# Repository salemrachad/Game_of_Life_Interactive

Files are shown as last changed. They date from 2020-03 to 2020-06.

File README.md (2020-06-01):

<p align="center">

</p>
                                          Interactive Painting

**I am building an interactive painting for my digital fabrication masters @ IED Madrid**  
check complete documentation on my wiki page : *https://github.com/salemrachad/Interactive_Painting/wiki*

* The IoT interactive painting can hang by your front door or a hallway...
When the painting senses motion, i.e someone exiting/entering the apartment it
will display the Weather Information or snap a picture and use it as the initial
state for Conway's Game of life.  Where the idea is that life doesn't only happen to you.
At some level you create it. So your presence is essence in that exchange.
  * *https://github.com/salemrachad/Interactive_Painting/wiki/0.0-Concept*

* I am going to be using an Arduino nano 33 IoT to control WS2812b LED displays. It has a 
good price bends for creative shaping can connect multiple matrixes together and easily controlled
by the fastLED or Neopixel Library. Every LED on that requires 5 mA so make sure to do the correct calculations
and chose the correct power supply.
  * *https://github.com/salemrachad/Interactive_Painting/wiki/0.1-Setup*

* I am using openWeather API call to get the weather information needed.
  * *https://github.com/salemrachad/Interactive_Painting/wiki/1.0-Weather-Sprites*
  * *https://github.com/salemrachad/Interactive_Painting/wiki/1.2-WIFI---API---JSON*

* The Game of Life, also known simply as Life, is a cellular automaton devised by the British mathematician 
John Horton Conway in 1970. It is a zero-player game, meaning that its evolution is determined by its
initial state, requiring no further input.  
  * *https://github.com/salemrachad/Interactive_Painting/wiki/2.0-GOL-Rules*

* I am using Processing.exe to analyze color information and translate the image taken by the webcam to a 32 x 32 2D Matrix then pass it through serial to the Arduino. Sending a 1024 byte size array is a bit tricky and I am still working on it.
  * *https://github.com/salemrachad/Interactive_Painting/wiki/3.0-Interactive-display*

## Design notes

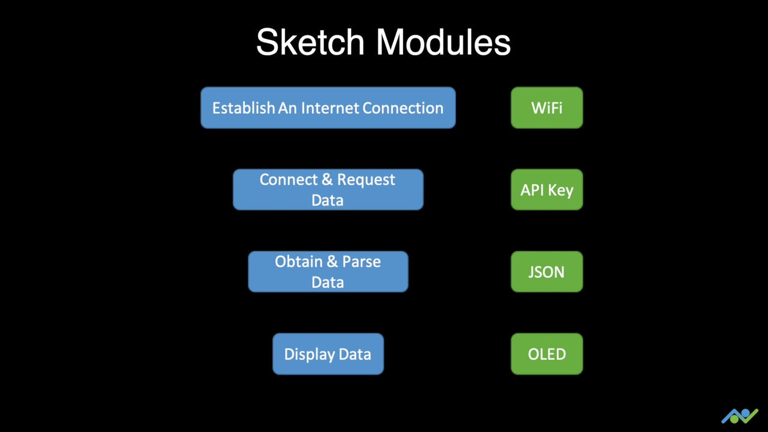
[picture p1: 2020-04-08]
Images/Wifi-Weather-Sketch.png

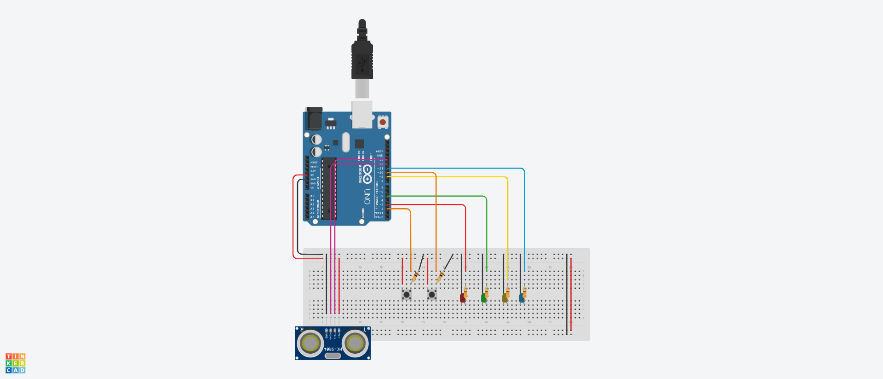
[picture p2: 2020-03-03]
Images/Arduino_Circuit.png

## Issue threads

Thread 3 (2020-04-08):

Lag when switching Cases

salemrachad, 2020-04-08:
I am having lag when switching between cases 1 and case 2.

salemrachad, 2020-04-12:
New issue when switching from Case 2 to Case 0 - Display Lag while connecting to openWeatherApi - not sure how to solve it yet

salemrachad, 2020-04-15:
Solved Lag between cases - I am having 5-10 sec of lag cycling from case 2 and case 1 - but that is the time for the HTTP request() to send and receive information - not sure if can make faster but I'll consider that issue closed for now

Closed 2020-04-15.

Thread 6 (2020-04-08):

Weather display

salemrachad, 2020-04-08:
After pulling weather data - I have to work on weather display on 32x32 LED matrix to represent weather. have 7 cases to work on

salemrachad, 2020-04-12:
Got the display to work from weather info - Still a primitive color display but will be changing it later on during the process.

salemrachad, 2020-04-15:
Initiated FastLED library to display processed images that I can store in Arduino Flash memory - using hexadecimal code

salemrachad, 2020-04-15:
Implemented only a Sun picture, for now, to see if it works and it was a SUCCESS - working on other weather display icons now.

salemrachad, 2020-04-16:
DONE!

Closed 2020-04-16.

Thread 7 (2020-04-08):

Send 2dArrat from Processing to Arduino Still not working

salemrachad, 2020-04-08:
I'm still figuring out how to send a 2d array via serial communication from processing to Arduino.
I start by sending a request from Arduino for 1 frame.
Hopefully, if I get this working I will implement many frames and make an interactive painting

salemrachad, 2020-04-15:
Case 2 - is activating a push buttonrequest from serial from Arduino part - and waiting for processing to answer - Still working on the code as it is not sending proper values

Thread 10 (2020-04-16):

Sprite animation stop before new httprequest

salemrachad, 2020-04-16:
Sprite animation is stopping before the new HTTP request. So I am having 1 frame display for 10 to 20 seconds before new weather information comes in. Trying to find a work around.

salemrachad, 2020-04-19:
Solved but now gstate can change while sprite animation is playing - trying different solutions.

salemrachad, 2020-04-21:
Cleared by extending sprite animation passtime

Closed 2020-04-21.

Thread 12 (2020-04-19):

deserializeJson() failed: NoMemory

salemrachad, 2020-04-19:
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

Sometimes serial is running this error --

salemrachad, 2020-04-21:
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

seems like there is enough memory- still trying to find a work around

salemrachad, 2020-04-21:
found a typing error - Last JSON_OBJECT_SIZE(14)+280 - change to JSON_OBJECT_SIZE(13)+270 and that solved it

Closed 2020-04-21.

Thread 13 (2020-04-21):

Change state button stuck again in Sprite animation

salemrachad, 2020-04-21:

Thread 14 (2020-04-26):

Add more narrative to help people understand the project in full

dcuartielles, 2020-04-26:
Hej,

I love your documentation, but if I didn't know what the project is all about, it would be really hard to understand what it is all about.

Please use a couple more hours in adding some narrative to your wiki, add licenses to the code, and then let's try to promote your project at e.g. the Arduino Blog and the like ;-)

/d

salemrachad, 2020-04-27:
Hey David,

I really appreciate it! I will be working on the repository and wiki this
week to make it clearer. As far as licensing goes, I am not sure how to
proceed. If you can point me in the right direction it would be great.

thank you

On Sun, Apr 26, 2020 at 11:06 AM dcuartielles <notifications@github.com>
wrote:

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

--
*Rachad Salem*
Architect

+1-714-350-1375

salemrachad@gmail.com

www.rachadsalem.com

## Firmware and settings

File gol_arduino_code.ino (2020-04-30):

///////////////////////////////////////////////////////////////////////////////////////////////////////////
// * Interactive Painting with 3 States
// *
// * State 0 gets weather information from OpenWeatherMap API and display
// * State 1 plays the game of GameofLife
// * State 2 is an interactive state using processing and webcam
// *
// * Written for the Arduino Nano 33 IoT Board and 4 x Longrunner WS2812B
// *
// * By Rachad Salem
//////////////////////////////////////////////////////////////////////////////////////////////////////////

//Wifi Setup

#include <WiFiNINA.h>
#include <ArduinoJson.h>
#include "arduino_secrets.h"
#include <stdio.h>
#include <SPI.h>

char ssid[] = SECRET_SSID;        // your network SSID (name)
char pass[] = SECRET_PASS;    // your network password (use for WPA, or use as key for WEP)
char api[] = OPENWEATHER_API; // your OpenWeatherMap API

int status = WL_IDLE_STATUS;

// Initialize the Wifi client library
WiFiSSLClient client;

unsigned long lastConnectionTime = 0;            // last time you connected to the server, in milliseconds
const unsigned long postingInterval = 30L * 1000L; // delay between updates, in milliseconds

//////////////////////////////////////////////////////////////////////////////////////////////////////////

//LED Setup - implementing Adafruit_NeoPixel and FastLED

#include <Adafruit_NeoPixel.h> //Adafruit_NeoPixel Library to display GameofLife_ram
#include "FastLED.h"       // Fastled library to control the LEDs
#include <avr/pgmspace.h>  // Needed to store stuff in Flash using PROGMEM

//DEFINE MATRIX 32x32
#define WIDTH 32
#define HEIGHT 32
#define PIN 6
#define NUMPIXELS 1024

Adafruit_NeoPixel pixels = Adafruit_NeoPixel(NUMPIXELS, PIN, NEO_GRB + NEO_KHZ800);

//color of the dots ({red, green, blue} max value 255 each] - Adafruit_NeoPixel
int colorOfPattern[3] = {25, 0, 25};
//color of background - Adafruit_NeoPixel
int colorOfBackground[3] = {0, 0, 0};
//Array for FastLed Matrix
CRGB leds[NUMPIXELS];
//////////////////////////////////////////////////////////////////////////////////////////////////////////

// Button Setup

const int buttonPin = 2; //Pause Button
int buttonState;
int lastButtonState = LOW;

const int buttonPin10 = 10; //Reset array Button
int buttonState10;
int lastButtonState10 = LOW;

const int buttonPin11 = 11; // Request Array from Processing Button
int buttonState11;
int lastButtonState11 = LOW;

const int buttonPin12 = 12; //State Changer Button
int buttonState12;
int lastButtonState12 = LOW;

// the following variables are unsigned longs because the time, measured in
// milliseconds, will quickly become a bigger number than can be stored in an int.
unsigned long lastDebounceTime = 0;  // the last time the output pin was toggled
unsigned long debounceDelay = 50;    // the debounce time; increase if the output flickers

//////////////////////////////////////////////////////////////////////////////////////////////////////////

//LED Setup

const int ledPin3 = 3; // RED Led Pin
int ledState3 = LOW;
const int ledPin5 = 5; // Green Led Pin
int ledState5 = LOW;
const int ledPin9 = 9; // Yellow Led Pin
int ledState9 = LOW;


//RGB LED setup - Display general Status by color

int Red_PIN = 14;    // gstatus 0
int Green_PIN = 15; // gstatus 1
int Blue_PIN = 16;//gstatus 2

//////////////////////////////////////////////////////////////////////////////////////////////////////////

//2d array

boolean array1[WIDTH][HEIGHT] ;
boolean cellbuffer[WIDTH][HEIGHT];

//////////////////////////////////////////////////////////////////////////////////////////////////////////

// Probability

float Probability = 45;

//////////////////////////////////////////////////////////////////////////////////////////////////////////

// Variables for timer

boolean pause = false;
int interval = 200;
int lastRecordedTime = 0;

//////////////////////////////////////////////////////////////////////////////////////////////////////////

//Variable for State
//implementing 3 states
//state 0 will Play game of life
//state 1 will display weather information on Led from OpenWeatherMap via Wifi
//state 2 will be an interactive LED - using processing and a webcam -

int gstate = 0;

///////////////////////////////////////////////////////////////////////////////////////////////////////////////////////////////////////////////////////////////////////////////////////////////////////////////////////////////////////////////////////////////////////////////////////////////////////////////////////////////////////

//Flash memory Stored Pictures for Weather Display

const long Clear1[] PROGMEM =
{
  0x99ccff, 0x99ccff, 0x99ccff, 0x99ccff, 0x99ccff, 0x99ccff, 0x99ccff, 0x99ccff, 0x99ccff, 0x99ccff, 0x99ccff, 0x99ccff, 0x99ccff, 0x99ccff, 0x99ccff, 0x99ccff, 0x99ccff, 0x99ccff, 0x99ccff, 0x99ccff, 0x99ccff, 0x99ccff, 0x99ccff, 0x99ccff, 0x99ccff, 0x99ccff, 0x99ccff, 0x99ccff, 0x99ccff, 0x99ccff, 0x99ccff, 0x99ccff,
  0x99ccff, 0x99ccff, 0x99ccff, 0x99ccff, 0x99ccff, 0x99ccff, 0x99ccff, 0x99ccff, 0x99ccff, 0x99ccff, 0x99ccff, 0x99ccff, 0x99ccff, 0x99ccff, 0x99ccff, 0x99ccff, 0x99ccff, 0x99ccff, 0x99ccff, 0x99ccff, 0x99ccff, 0x99ccff, 0x99ccff, 0x99ccff, 0x99ccff, 0x99ccff, 0x99ccff, 0x99ccff, 0x99ccff, 0x99ccff, 0x99ccff, 0x99ccff,
  0x99ccff, 0x99ccff, 0x99ccff, 0x99ccff, 0x99ccff, 0x99ccff, 0x99ccff, 0x99ccff, 0x99ccff, 0x99ccff, 0x99ccff, 0x99ccff, 0x99ccff, 0x99ccff, 0x99ccff, 0x99ccff, 0x99ccff, 0x99ccff, 0x99ccff, 0x99ccff, 0x99ccff, 0x99ccff, 0x99ccff, 0x99ccff, 0x99ccff, 0x99ccff, 0x99ccff, 0x99ccff, 0x99ccff, 0x99ccff, 0x99ccff, 0x99ccff,
  0x99ccff, 0x99ccff, 0x99ccff, 0x99ccff, 0x99ccff, 0x99ccff, 0x99ccff, 0x99ccff, 0x99ccff, 0x99ccff, 0x99ccff, 0x99ccff, 0x99ccff, 0x99ccff, 0x99ccff, 0x99ccff, 0x99ccff, 0x99ccff, 0x99ccff, 0xffffff, 0xffffff, 0xffffff, 0xffffff, 0xffffff, 0xffffff, 0xffffff, 0x99ccff, 0x99ccff, 0x99ccff, 0x99ccff, 0x99ccff, 0x99ccff,
  0x99ccff, 0x99ccff, 0x99ccff, 0x99ccff, 0xffffff, 0xffffff, 0x99ccff, 0x99ccff, 0x99ccff, 0x99ccff, 0x99ccff, 0x99ccff, 0xffffff, 0xffffff, 0xffffff, 0x99ccff, 0x99ccff, 0x99ccff, 0x99ccff, 0x99ccff, 0x99ccff, 0x99ccff, 0x99ccff, 0x99ccff, 0x99ccff, 0x99ccff, 0x99ccff, 0x99ccff, 0x99ccff, 0x99ccff, 0x99ccff, 0x99ccff,
  0x99ccff, 0x99ccff, 0xffffff, 0x99ccff, 0x99ccff, 0x99ccff, 0x99ccff, 0x99ccff, 0x99ccff, 0x99ccff, 0x99ccff, 0x99ccff, 0x99ccff, 0x99ccff, 0x99ccff, 0x99ccff, 0xffffff, 0xffffff, 0x99ccff, 0x99ccff, 0x99ccff, 0x99ccff, 0x99ccff, 0x99ccff, 0x99ccff, 0x99ccff, 0x99ccff, 0x99ccff, 0xffffff, 0xffffff, 0x99ccff, 0x99ccff,
  0x99ccff, 0x99ccff, 0xffffff, 0x99ccff, 0x99ccff, 0x99ccff, 0x99ccff, 0x99ccff, 0x99ccff, 0x99ccff, 0x99ccff, 0x99ccff, 0x99ccff, 0x99ccff, 0x99ccff, 0xffffff, 0xffffff, 0x99ccff, 0x99ccff, 0x99ccff, 0x99ccff, 0x99ccff, 0x99ccff, 0x99ccff, 0x99ccff, 0x99ccff, 0x99ccff, 0x99ccff, 0xffffff, 0xffffff, 0x99ccff, 0x99ccff,
  0x99ccff, 0x99ccff, 0x99ccff, 0xffffff, 0x99ccff, 0x99ccff, 0x99ccff, 0x99ccff, 0x99ccff, 0x99ccff, 0x99ccff, 0x99ccff, 0x99ccff, 0x99ccff, 0xffffff, 0xffffff, 0x99ccff, 0x99ccff, 0x99ccff, 0x99ccff, 0x99ccff, 0x99ccff, 0x99ccff, 0x99ccff, 0x99ccff, 0x99ccff, 0x99ccff, 0x99ccff, 0x99ccff, 0xffffff, 0x99ccff, 0x99ccff,
  0x99ccff, 0x99ccff, 0x99ccff, 0x99ccff, 0x99ccff, 0x99ccff, 0x99ccff, 0x99ccff, 0x99ccff, 0x99ccff, 0x99ccff, 0x99ccff, 0x99ccff, 0x99ccff, 0x99ccff, 0x99ccff, 0x99ccff, 0xffffff, 0xffffff, 0x99ccff, 0x99ccff, 0x99ccff, 0x99ccff, 0x99ccff, 0x99ccff, 0x99ccff, 0xffffff, 0xffffff, 0x99ccff, 0x99ccff, 0x99ccff, 0x99ccff,
  0x99ccff, 0x99ccff, 0x99ccff, 0x99ccff, 0x99ccff, 0xffffff, 0xffffff, 0xffffff, 0x99ccff, 0x99ccff, 0x99ccff, 0xffffff, 0xffffff, 0xffffff, 0x99ccff, 0x99ccff, 0x99ccff, 0x99ccff, 0x99ccff, 0x99ccff, 0x99ccff, 0x99ccff, 0x99ccff, 0x99ccff, 0x99ccff, 0x99ccff, 0x99ccff, 0x99ccff, 0x99ccff, 0x99ccff, 0x99ccff, 0x99ccff,
  0x99ccff, 0x99ccff, 0x99ccff, 0x99ccff, 0x99ccff, 0x99ccff, 0x99ccff, 0x99ccff, 0x99ccff, 0x99ccff, 0x99ccff, 0x99ccff, 0x99ccff, 0x99ccff, 0x99ccff, 0x99ccff, 0x99ccff, 0x99ccff, 0x99ccff, 0x99ccff, 0xffffff, 0xffffff, 0xffffff, 0xffffff, 0xffffff, 0x99ccff, 0x99ccff, 0x99ccff, 0x99ccff, 0x99ccff, 0x99ccff, 0x99ccff,
  0x99ccff, 0x99ccff, 0x99ccff, 0x99ccff, 0x99ccff, 0x99ccff, 0x99ccff, 0x99ccff, 0x99ccff, 0x99ccff, 0x99ccff, 0x99ccff, 0x99ccff, 0x99ccff, 0x99ccff, 0x99ccff, 0x99ccff, 0x99ccff, 0x99ccff, 0x99ccff, 0x99ccff, 0x99ccff, 0x99ccff, 0x99ccff, 0x99ccff, 0x99ccff, 0x99ccff, 0x99ccff, 0x99ccff, 0x99ccff, 0x99ccff, 0x99ccff,
  0x99ccff, 0x99ccff, 0x99ccff, 0x99ccff, 0x99ccff, 0x99ccff, 0x99ccff, 0x99ccff, 0x99ccff, 0x99ccff, 0x99ccff, 0x99ccff, 0x99ccff, 0xffffff, 0xffffff, 0xffffff, 0x99ccff, 0x99ccff, 0x99ccff, 0x99ccff, 0x99ccff, 0x99ccff, 0x99ccff, 0x99ccff, 0x99ccff, 0x99ccff, 0x99ccff, 0x99ccff, 0x99ccff, 0x99ccff, 0x99ccff, 0x99ccff,
  0x99ccff, 0x99ccff, 0x99ccff, 0x99ccff, 0x99ccff, 0x99ccff, 0x99ccff, 0x99ccff, 0x99ccff, 0x99ccff, 0x99ccff, 0x99ccff, 0x99ccff, 0x99ccff, 0xffffff, 0xffffff, 0xffffff, 0x99ccff, 0x99ccff, 0x99ccff, 0x99ccff, 0x99ccff, 0x99ccff, 0x99ccff, 0x99ccff, 0x99ccff, 0x99ccff, 0x99ccff, 0x99ccff, 0x99ccff, 0x99ccff, 0x99ccff,
  0x99ccff, 0x99ccff, 0x99ccff, 0x99ccff, 0x99ccff, 0x99ccff, 0x99ccff, 0x99ccff, 0x99ccff, 0x99ccff, 0x99ccff, 0x99ccff, 0x99ccff, 0x99ccff, 0x99ccff, 0x99ccff, 0x99ccff, 0xffffff, 0xffffff, 0x99ccff, 0x99ccff, 0x99ccff, 0x99ccff, 0x99ccff, 0x99ccff, 0x99ccff, 0x99ccff, 0x99ccff, 0x99ccff, 0x99ccff, 0x99ccff, 0x99ccff,
  0x99ccff, 0x99ccff, 0x99ccff, 0x99ccff, 0xffffff, 0x99ccff, 0x99ccff, 0x99ccff, 0x99ccff, 0x99ccff, 0x99ccff, 0x99ccff, 0xffffff, 0xffffff, 0x99ccff, 0x99ccff, 0x99ccff, 0x99ccff, 0x99ccff, 0x99ccff, 0x99ccff, 0x99ccff, 0x99ccff, 0x99ccff, 0x99ccff, 0x99ccff, 0x99ccff, 0x99ccff, 0x99ccff, 0x99ccff, 0x99ccff, 0x99ccff,
  0x99ccff, 0x99ccff, 0x99ccff, 0x99ccff, 0x99ccff, 0x99ccff, 0x99ccff, 0x99ccff, 0x99ccff, 0x99ccff, 0x99ccff, 0x99ccff, 0x99ccff, 0x99ccff, 0x99ccff, 0x99ccff, 0x99ccff, 0x99ccff, 0x99ccff, 0xffffff, 0xffffff, 0x99ccff, 0x99ccff, 0x99ccff, 0xffffff, 0xffffff, 0xffffff, 0xffffff, 0x99ccff, 0x99ccff, 0x99ccff, 0x99ccff,
  0x99ccff, 0x99ccff, 0x99ccff, 0x99ccff, 0x99ccff, 0x99ccff, 0x99ccff, 0xffffff, 0xffffff, 0xffffff, 0xffffff, 0x99ccff, 0x99ccff, 0x99ccff, 0x99ccff, 0x99ccff, 0x99ccff, 0x99ccff, 0x99ccff, 0x99ccff, 0x99ccff, 0xffffff, 0xffffff, 0xffffff, 0x99ccff, 0x99ccff, 0x99ccff, 0x99ccff, 0x99ccff, 0x99ccff, 0x99ccff, 0x99ccff,
  0x99ccff, 0x99ccff, 0x99ccff, 0x99ccff, 0x99ccff, 0xffffff, 0xffffff, 0xffffff, 0xffffff, 0x99ccff, 0xffffff, 0xffffff, 0xffffff, 0x99ccff, 0x99ccff, 0x99ccff, 0x99ccff, 0x99ccff, 0x99ccff, 0x99ccff, 0x99ccff, 0x99ccff, 0x99ccff, 0x99ccff, 0x99ccff, 0x99ccff, 0x99ccff, 0x99ccff, 0x99ccff, 0x99ccff, 0x99ccff, 0x99ccff,
  0x99ccff, 0x99ccff, 0x99ccff, 0x99ccff, 0x99ccff, 0x99ccff, 0x99ccff, 0x99ccff, 0x99ccff, 0x99ccff, 0x99ccff, 0x99ccff, 0x99ccff, 0x99ccff, 0x99ccff, 0x99ccff, 0x99ccff, 0x99ccff, 0xffffff, 0xffffff, 0x99ccff, 0x99ccff, 0x99ccff, 0x99ccff, 0x99ccff, 0x99ccff, 0xffffff, 0xffffff, 0x99ccff, 0x99ccff, 0x99ccff, 0x99ccff,
  0x99ccff, 0x99ccff, 0x99ccff, 0xffffff, 0xffffff, 0x99ccff, 0x99ccff, 0x99ccff, 0x99ccff, 0x99ccff, 0x99ccff, 0x99ccff, 0x99ccff, 0xffffff, 0xffffff, 0xffffff, 0x99ccff, 0x99ccff, 0x99ccff, 0x99ccff, 0x99ccff, 0x99ccff, 0x99ccff, 0x99ccff, 0x99ccff, 0x99ccff, 0xffffff, 0xffffff, 0x99ccff, 0x99ccff, 0x99ccff, 0x99ccff,
  0x99ccff, 0x99ccff, 0x99ccff, 0x99ccff, 0x99ccff, 0xffffff, 0xffffff, 0x99ccff, 0x99ccff, 0x99ccff, 0x99ccff, 0x99ccff, 0x99ccff, 0x99ccff, 0x99ccff, 0xffffff, 0xffffff, 0x99ccff, 0x99ccff, 0x99ccff, 0x99ccff, 0x99ccff, 0x99ccff, 0x99ccff, 0x99ccff, 0x99ccff, 0x99ccff, 0x99ccff, 0xffffff, 0xffffff, 0x99ccff, 0x99ccff,
  0x99ccff, 0x99ccff, 0xffffff, 0x99ccff, 0x99ccff, 0x99ccff, 0x99ccff, 0x99ccff, 0x99ccff, 0x99ccff, 0x99ccff, 0x99ccff, 0x99ccff, 0x99ccff, 0x99ccff, 0x99ccff, 0xffffff, 0xffffff, 0xffffff, 0x99ccff, 0x99ccff, 0x99ccff, 0x99ccff, 0xffffff, 0xffffff, 0xffffff, 0x99ccff, 0x99ccff, 0x99ccff, 0x99ccff, 0x99ccff, 0x99ccff,
  0x99ccff, 0x99ccff, 0x99ccff, 0x99ccff, 0x99ccff, 0x99ccff, 0x99ccff, 0x99ccff, 0xffffff, 0xffffff, 0xffffff, 0xffffff, 0xffffff, 0xffffff, 0x99ccff, 0x99ccff, 0x99ccff, 0x99ccff, 0x99ccff, 0x99ccff, 0x99ccff, 0x99ccff, 0x99ccff, 0x99ccff, 0x99ccff, 0x99ccff, 0x99ccff, 0x99ccff, 0x99ccff, 0x99ccff, 0x99ccff, 0x99ccff,
  0x99ccff, 0x99ccff, 0x99ccff, 0x99ccff, 0x99ccff, 0x99ccff, 0x99ccff, 0x99ccff, 0x99ccff, 0x99ccff, 0x99ccff, 0x99ccff, 0x99ccff, 0x99ccff, 0x99ccff, 0x99ccff, 0x99ccff, 0x99ccff, 0x99ccff, 0x99ccff, 0x99ccff, 0x99ccff, 0x99ccff, 0x99ccff, 0x99ccff, 0x99ccff, 0x99ccff, 0x99ccff, 0x99ccff, 0x99ccff, 0x99ccff, 0x99ccff,
  0x99ccff, 0x99ccff, 0x99ccff, 0x99ccff, 0x99ccff, 0x99ccff, 0x99ccff, 0x99ccff, 0x99ccff, 0x99ccff, 0x99ccff, 0x99ccff, 0x99ccff, 0x99ccff, 0x99ccff, 0x99ccff, 0x99ccff, 0x99ccff, 0x99ccff, 0x99ccff, 0x99ccff, 0x99ccff, 0x99ccff, 0x99ccff, 0x99ccff, 0x99ccff, 0x99ccff, 0x99ccff, 0x99ccff, 0x99ccff, 0x99ccff, 0x99ccff,
  0x99ccff, 0x99ccff, 0x99ccff, 0x99ccff, 0x99ccff, 0x99ccff, 0x99ccff, 0x99ccff, 0x99ccff, 0x99ccff, 0x99ccff, 0x99ccff, 0x99ccff, 0x99ccff, 0x99ccff, 0x99ccff, 0x99ccff, 0x99ccff, 0x99ccff, 0x99ccff, 0x99ccff, 0x99ccff, 0x99ccff, 0x99ccff, 0x99ccff, 0x99ccff, 0x99ccff, 0x99ccff, 0x99ccff, 0x99ccff, 0x99ccff, 0x99ccff,
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
void loop() {

  //Change State Button and LED
  button_changeState();
  stateLedColor();

  // 3 Different States for the Painting
  switch (gstate) {

    case 0: //Weather Call/Display
      if (millis() - lastConnectionTime > postingInterval)
      {
        httpRequest();
      }
      break;

    case 1: //Game of Life
      pauseGame();
      pauseButton();
      resetButton();
      break;

    case 2: //Interactive module
      button_requestArrayFromSerial();
      pixels.clear();
      for (int i = 0; i < WIDTH * HEIGHT; i++) {
        pixels.setPixelColor(i, pixels.Color(5, 5, 0 ));
      }
      pixels.show();
      break;
  }
}

void initializeCells() {  //Initial state for game of life with Probability 45% chance alive
  for (int i = 0; i < WIDTH; i++) {
    for (int j = 0; j < HEIGHT; j++) {
      float state = random (100);
      if (state > Probability) {
        state = 0;
      }
      else {
        state = 1;
      }
      array1[i][j] = int(state); // Save state of each cell
    }
  }
}

void GameofLife_ram() { //Game of life memory
  for (int i = 0; i < WIDTH; i++) {
    for (int j = 0; j < HEIGHT; j++) {
      cellbuffer[i][j] = array1[i][j];
    }
  }
  // Visit each cell:
  for (int i = 0; i < WIDTH; i++) {
    for (int j = 0; j < HEIGHT; j++) {
      int neighbours = 0; //  count the neighbours
      for (int ii = i - 1; ii <= i + 1; ii++) {
        for (int jj = j - 1; jj <= j + 1; jj++) {
          if (((ii >= 0) && (ii < WIDTH)) && ((jj >= 0) && (jj < HEIGHT))) { //check if out of bounds
            if (!((ii == i) && (jj == j))) { // Make sure to to check against self
              if (cellbuffer[ii][jj] == 1) {
                neighbours ++; // Check alive neighbours and count them
              }
            } // End of if
          } // End of if
        } // End of jj loop
      } //End of ii loop

      // We've checked the neigbours - apply rules
      if (cellbuffer[i][j] == 1) { // The cell is alive: kill it if
        if (neighbours < 2 || neighbours > 3) {
          array1[i][j] = 0; // Die unless it has 2 or 3 neighbours
        }
      }
      else { // The cell is dead: make it live if necessary
        if (neighbours == 3 ) {
          array1[i][j] = 1; // Only if it has 3 neighbours
        }
      } // End of if
    } // End of j loop
  } //End of i loop
} //End of function

void statePlot() { //Plot Game of life on LED
  int alive;
  //int bright1 = proxibrightness();
  for (int i = 0; i < WIDTH; i++) {
    for (int j = 0; j < HEIGHT; j++) {

      if (j & 0x1) { //is odd
        if (array1[i][j] == 1) {
          pixels.setPixelColor(((j * WIDTH) + (WIDTH - 1 - i)), pixels.Color(colorOfPattern[0], colorOfPattern[1], colorOfPattern[2])); // Plot left to right
          alive++;
        }
        else {
          pixels.setPixelColor(((j * WIDTH) + (WIDTH - 1 - i)), pixels.Color(colorOfBackground[0], colorOfBackground[0], colorOfBackground[0])); //is even - Plot right to left
        }
      }
      else {
        if (array1[i][j] == 1) {
          pixels.setPixelColor(i + (j * WIDTH) , pixels.Color(colorOfPattern[0], colorOfPattern[1], colorOfPattern[2])); // Plot left to right
          alive++;
        }
        else {
          pixels.setPixelColor(i + (j * WIDTH), pixels.Color(colorOfBackground[0], colorOfBackground[0], colorOfBackground[0])); //is even - Plot right to left
        }
      }
    }
  }
  pixels.show();
  if (alive <= int(NUMPIXELS * 0.039)) { // if number of alive pixels < 40 Reset Game of life - Will allow game to reset when static
    initializeCells();
  }
}

void pauseButton() {
  pinMode(ledPin5, OUTPUT);

  int reading = digitalRead(buttonPin);
  // If the switch changed, due to noise or pressing:
  if (reading != lastButtonState) {
    // reset the debouncing timer
    lastDebounceTime = millis();
  }
  if ((millis() - lastDebounceTime) > debounceDelay) {
    // whatever the reading is at, it's been there for longer than the debounce
    // delay, so take it as the actual current state:

    // if the button state has changed:
    if (reading != buttonState) {
      buttonState = reading;

      // only toggle Pause if the new button state is HIGH
      if (buttonState == HIGH) {
        pause = !pause;
      }
    }
  }
  lastButtonState = reading;

  if (pause == false) {
    ledState5 = HIGH;
    digitalWrite(ledPin5, ledState5);
  } else if (pause == true) {
    ledState5 = LOW;
    digitalWrite(ledPin5, ledState5);
  }
}

void resetButton() {

  int reading = digitalRead(buttonPin10);
  // If the switch changed, due to noise or pressing:
  if (reading != lastButtonState10) {
    // reset the debouncing timer
    lastDebounceTime = millis();
  }
  if ((millis() - lastDebounceTime) > debounceDelay) {
    // whatever the reading is at, it's been there for longer than the debounce
    // delay, so take it as the actual current state:

    // if the button state has changed:
    if (reading != buttonState10) {
      buttonState10 = reading;
      // only toggle Reset if the new button state is HIGH
      if (buttonState10 == HIGH) {
        initializeCells();
      }
    }
  }
  lastButtonState10 = reading;
}

void button_requestArrayFromSerial() {

  int reading = digitalRead(buttonPin11);
  // If the switch changed, due to noise or pressing:
  if (reading != lastButtonState11) {
    // reset the debouncing timer
    lastDebounceTime = millis();
  }
  if ((millis() - lastDebounceTime) > debounceDelay) {
    // whatever the reading is at, it's been there for longer than the debounce
    // delay, so take it as the actual current state:

    // if the button state has changed:
    if (reading != buttonState11) {
      buttonState11 = reading;
      // Send request to Processing if the new button state is HIGH
      if (buttonState11 == HIGH) {
        //start request
      }
    }
  }
  lastButtonState11 = reading;
}

void button_changeState() {

  int reading = digitalRead(buttonPin12);

  // If the switch changed, due to noise or pressing:
  if (reading != lastButtonState12) {
    // reset the debouncing timer
    lastDebounceTime = millis();
  }
  if ((millis() - lastDebounceTime) > debounceDelay) {
    // whatever the reading is at, it's been there for longer than the debounce
    // delay, so take it as the actual current state:

    // if the button state has changed:
    if (reading != buttonState12) {
      buttonState12 = reading;

      // only toggle if the new button state is HIGH
      if (buttonState12 == HIGH) {
        pixels.clear();
        gstate = gstate + 1;
      }
    }
  }
  lastButtonState12 = reading;
}

void stateLedColor() {  //RGB LED color depending on gstate.

  pinMode(Red_PIN, OUTPUT);
  pinMode(Green_PIN, OUTPUT);
  pinMode(Blue_PIN, OUTPUT);
  pinMode(ledPin5, OUTPUT);

  if (gstate == 0) {        //Color Red if gstate=0
    analogWrite(Red_PIN, 255);
    analogWrite(Green_PIN, 0);
    analogWrite(Blue_PIN, 0);
  }
   else if (gstate == 1) { //Color Green if gstate=1
    analogWrite(Red_PIN, 0);
    analogWrite(Green_PIN, 255);
    analogWrite(Blue_PIN, 0);
  }
  else if (gstate == 2) { //Color Blue if gstate=2
    analogWrite(Red_PIN, 0);
    analogWrite(Green_PIN, 0);
    analogWrite(Blue_PIN, 255);
  }
   else if (gstate >= 3) {  //Reset if gstate=0 to maintain only 3 switch cases
    gstate = 0;
  }
}

void pauseGame() {
  if (millis() - lastRecordedTime > interval) {
    if (!pause) {
      GameofLife_ram();
      statePlot();
      lastRecordedTime = millis();
    }
  }
}

void connect2Wifi() {
  pinMode(ledPin3, OUTPUT);
  pinMode(ledPin9, OUTPUT);
  // check for the WiFi module:
  if (WiFi.status() == WL_NO_MODULE)
  {
    Serial.println("Communication with WiFi module failed!");
    // don't continue
    while (true);
  }

  String fv = WiFi.firmwareVersion();
  if (fv < "1.0.0")
  {
    Serial.println("Please upgrade the firmware");
  }

  // attempt to connect to Wifi network:
  while (status != WL_CONNECTED)
  {
    digitalWrite(ledPin3, HIGH);
    digitalWrite(ledPin9, LOW);
    Serial.print("Attempting to connect to SSID: ");
    Serial.println(ssid);
    // Connect to WPA/WPA2 network. Change this line if using open or WEP network:
    status = WiFi.begin(ssid, pass);
    // wait 10 seconds for connection:
    delay(10000);
  }
  // you're connected now, so print out the status:
  digitalWrite(ledPin3, LOW);
  digitalWrite(ledPin9, HIGH);
  printWifiStatus();

}
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

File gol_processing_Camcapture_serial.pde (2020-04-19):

import processing.video.*;
import processing.serial.*;

Serial myPort;  // Create object from Serial class
int val;        // Data received from the serial port

Capture cam;


int[][] ProcessingledMatrix;
int BWrez =250;
int ledxnumber=32;
int ledynumber=32;
String str;
boolean firstContact = false;

void setup() {
  size(640, 360);

  String portName = Serial.list()[0];
  print(portName);
  myPort = new Serial(this, portName, 115200);
  initializeCam();
}

void draw() {
}

void initializeCam() {
  String[] cameras = Capture.list();

  if (cameras.length == 0) {
    println("There are no cameras available for capture.");
    exit();
  } else {
    println("Available cameras:");
    for (int i = 0; i < cameras.length; i++) {
      println(cameras[i]);
    }
    // The camera can be initialized directly using an
    // element from the array returned by list():
    cam = new Capture(this, cameras[11]);
    cam.start();
  }
}

void processImage() {
  PImage img = loadImage("C:/Users/racha/desktop/image/silh_1.jpg");


  int xled = width/ledxnumber;
  int yled = height/ledynumber;

  ProcessingledMatrix = new int[ledxnumber][ledynumber];

  //Draw LED MATRIX GRID

  for (int i=0; i<width; i+=xled) {
    for (int j=0; j<height; j+=yled) {
      PImage newImg = img.get(i, j, xled, yled);
      fill(extractColorFromImage(newImg));
      rect(i, j, xled, yled);
    }
  }
  save("C:/Users/racha/desktop/image/silh_1_frag.jpg");
  //sendtoArduino(ProcessingledMatrix);
}
//Get the average RGB from pixels

color extractColorFromImage(PImage img) {

  img.loadPixels();
  int r = 0, g = 0, b = 0;
  for (int i=0; i<img.pixels.length; i++) {
    color c = img.pixels[i];
    r += c>>16&0xFF;
    g += c>>8&0xFF;
    b += c&0xFF;
  }
  r /= img.pixels.length;
  g /= img.pixels.length;
  b /= img.pixels.length;

  //sums the rgb to calculate brightness
  //closer to 0 is black |||||| closer to 255 is white
  //implement if loop to make colors binary- Calibrate

  int sum = r +g + b;

  for (int i=0; i<ledxnumber; i++) {
    for (int j=0; j<ledynumber; j++) {
      int state=0;
      if (sum <BWrez) {
        r=0;
        g=0;
        b=0;
        state=1;
      } else if (sum>BWrez) {
        r=255;
        g=255;
        b=255;
        state=0;
      }
      ProcessingledMatrix[i][j]=state;
      print(ProcessingledMatrix[i][j]);
    }
  }
  return color(r, g, b);
}

void serialEvent(Serial myPort) {

  // read a byte from the serial port:
  int inByte = myPort.read();

  if (inByte == 'A') {
    println("Arduino is requesting Array");
    key = 'r';
    key= ' ';
    myPort.clear();
  }
}

void SnapShot() {
  if (cam.available() == true) {
    cam.read();
    cam.filter(GRAY);
    image (cam, 0, 0);
    saveFrame("C:/Users/racha/desktop/image/silh_1.jpg");
  }
}

void keyPressed() {
  if (key == 'r') {
    SnapShot();
    delay(300);
    processImage();
    delay(300);
    sendtoArduino(ProcessingledMatrix);
  }
}

void sendtoArduino(int[][] _ProcessingledMatrix) {
  byte out[] = new byte[ledxnumber*ledynumber];
  for (int i=0; i<ledxnumber; i++) {
    for (int j=0; j<ledynumber; j++) {
      out[i+j] = (byte)_ProcessingledMatrix[i][j];
    }
  }
  myPort.write(out);
}

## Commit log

2020-03-03 Add files via upload
    Arduino code I have so far. Receiving Processing array through Serial is still being developed.
2020-03-03 Add files via upload
    Processing code to take a picture from webcam and turn it into a 2d Binary array. Send to Arduino through serial communication.
    next step is evolving serial to wifi
2020-03-23 Update gol_arduino_code.ino
    updated code to work on arduino iot nano 33 and some cleanups
2020-03-30 Fixed ram to matrix translation issues
    //pixels.setPixelColor(((j * WIDTH) + (WIDTH - 1 - i)), pixels.Color(25, 0, 25)); for odd rows
    //pixels.setPixelColor(i + (j * WIDTH), pixels.Color(0, 0, 0)); for even rows
    [gol_arduino_code.ino]
2020-04-01 Changed some LED variables
2020-04-08 Update gol_arduino_code.ino
    Implemented new buttons and cases
    cycle gstate for cases button
    snap from processing button
    case 0 : play game of life
    case 1 : Display weather info(in progress)
    case 2 : Interactive display from processing webcam(in progress)
    [gol_arduino_code.ino]
2020-04-12 Wifi module modifications
    Added Wifi setup
    linked lights to display wifi connection
    Display Weather on 32x32 LED matrix in different Colors
2020-04-15 Implemented Flash memory and Fast LED for Weather Display
    Storing images on arduino flash memory for weather display using FastLED -
    Still using Adafruit_Neopixel for GOL display-
2020-04-15 compartmentalizing the send and request
    compartmentalizing the call/response to make it easier with 1 button push
2020-04-17 Adjusted sprite display animation lenght to fill gap between HttpRequests
    [Interactive Painting - IED-PCB.fzz]
2020-04-19 Send array to arduino test 24
    [Interactive Painting - IED-PCB.fzz]
2020-04-20 Fixed gstate and sprite animation time
    Code was getting stuck in Sprite animation preventing the change state button from working.
    Also reduced sprite animation time from 30 to 20
    [gol_arduino_code.ino]
2020-04-21 Minor fixes
    Fixed JSON no memory issue.
    turns out it was a typo in the parsing code.
    [Interactive Painting - IED-PCB.fzz]
